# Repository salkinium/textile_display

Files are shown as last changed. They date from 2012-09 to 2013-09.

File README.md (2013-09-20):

Luminet2 Textile Display
========================

The Luminet2 Textile Display is a demonstrator for using the 
[Luminet2 Smart Pixel][luminet2] to display content on a flexible surface.
It consists out of an iOS App, many Luminet2 pixels and a textile connection matrix.

The project was done as a collaboration between [The Media Computing Group][i10] and
the [Institut für Textiltechnik][ITA] at RWTH Aachen University.

The main design goals of this project were to:

-	create a high density flexible display using Luminet2 pixels,
-	use a economically viable production technology,
-	design a scalable communication protocol.

The display is then to be integrated into a pillow case which protects the
display and encapsulates the battery and wireless communication adapter.

Design Concept
--------------

We received 80 Luminet2 pixels and decided to limit the display resolution to
8 x 8 pixels for a total of 64 pixels used.
The remaining pixels were used to testing connection techniques and buffer.

For the display to work, these four problems had to be solved:

1.	The pixels need to be connected with each other and placed on a textile
	using an industrial manufacturing technique
3.	A scalable method of communication between the pixels is required.
4.	The display should easily be connected to external data sources.

### Connection matrix

A matrix of flexible enameled copper wire was attached to jeans textile using
a CNC embroilment machine.
The wires have the function of fixing the Luminet2 PCB to the textile as
well as providing it with power and communication abilities.  
The design process is [described here][design].

### Communication

All pixels can exchange information between each other and an external node.  
Internally all nodes are attached to a wired ring bus, which is based on serial
communication and runs at high speed (0.5MBaud).
This bus is simply connected to a WiFly module which enables transparent
communication over WiFi using TCP/IP.  
Further information about [the embedded software][embedded].

### iOS app

An iOS application allow the drawing of custom 8x8 textures as well as
scrolling text in different colors and fonts.  
A UI description can be [found here][ui]

Organisation
------------

This repository is organized as follows:

-	The *connection* folder the python generators for the vector files for the 
	textile connection matrix.
- 	The *module* folder contains the embedded code for the Luminet2 pixels.
-	The *Textplay* folder contains the iOS App to control the display.

The Luminet2 Smart Pixel were designed by [Mariana Bocoi][bocoi].  
The connection matrix and embedded software were designed by [Niklas Hauser][hauser].

[luminet2]: http://hci.rwth-aachen.de/luminet2
[i10]: http://hci.rwth-aachen.de
[ita]: http://www.ita.rwth-aachen.de
[bocoi]: http://hci.rwth-aachen.de/bocoi
[hauser]: http://hci.rwth-aachen.de/hauser
[design]: https://amedeo.informatik.rwth-aachen.de/groups/textiledisplay/wiki/0f695/Textile_Connection_Matrix.html
[embedded]: https://amedeo.informatik.rwth-aachen.de/groups/textiledisplay/wiki/de7d8/Embedded_Software.html
[ui]: https://amedeo.informatik.rwth-aachen.de/groups/textiledisplay/wiki/711c2/Textplay_iOS_App.html

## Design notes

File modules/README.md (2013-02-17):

Luminet2 Pixel Software
=======================

The sources are compiled using the [XPCC library][xpcc], which is used for
GPIO, Processing, Build System and Serial Debugging.

Color generation
----------------

The color is generated using 8-bit PWM and a [gamma-corrected][gamma] look-up
table stored in flash memory.
This guarantees fast access times and correct color perception, however
generating very dark colors does not yield good results due to limited
PWM value range.

Photosensitive Diode
--------------------

Light intensity is measured using an oversampling and averaging algorithm.
The results are currently not used.

Communication
-------------

To transfer the bitmap data into the display, a simplified Resilient Packet Ring
protocol is used over serial.
The data is split into four 48-byte packets, which are sent as multicasts to
16 pixels each.
This allows for a small buffer on each pixel with acceptable overhead.

Each pixel has a unique 15bit address, and belongs to one of the four group
addresses, which are stored in EEPROM.
The bitmap values are sent as 8bit RGB values, and the node then calculated
the offset of its values in the data.

The protocol is currently not yet fully implemented, and still in development
at XPCC, however basic functionality, such as sending and receiving messages
works.

A more detailed description of the frame format [can be found here][rpr].

The pixels communicate directly with a WiFly module in ad-hoc mode, at a
baudrate of 0.5Mbps (500000 bits/s).

Firmware
--------

The sources are compiled using the [XPCC library][xpcc], which is used for
GPIO, Processing, Build System and Serial Debugging.  
Enter the `source` directory

	$ cd /path/to/textile_display/modules/source

To compile, execute:

	$ scons

To set the fuses on the microcontroller, execute:

	$ scons fuse

To flash the binary onto the microcontroller, execute:

	$ scons program

The fuses are set at 0xef (low), 0xd1 (high), 0x07 (extended).  
You can set the fuses manually using this command:

	$ avrdude -p atmega328p -c avrispmkii -P usb -u \
	-U hfuse:w:0xd1:m -U efuse:w:0x07:m -U lfuse:w:0xef:m

Installing XPCC
---------------

XPCC is provided as a git submodule, to use it run this in the root directory:

	$ git submodule init
	$ git submodule update

To install the XPCC build system on OS X (tested on Lion/Mountain Lion):

1.	Install [Homebrew][]:  
	`$ ruby -e "$(curl -fsSL https://raw.github.com/mxcl/homebrew/go)"`
2.	Install some dependencies:  
	`$ brew install scons python`  
	`$ pip install lxml jinja2`
3.	Install the latest precompiled version of [avr-gcc from ObDev][obdev].

To install the XPCC build system on Linux (tested on Ubuntu 12.04):

	$ sudo apt-get update
	$ sudo apt-get install python scons python-jinja2 python-lxml \
	gcc-avr binutils-avr avr-libc avrdude

Extensive information on installing [the XPCC build system can be found here][xpcc-install].

[xpcc]: https://github.com/roboterclubaachen/xpcc
[gamma]: http://en.wikipedia.org/wiki/Gamma_correction
[rpr]: https://raw.github.com/roboterclubaachen/xpcc/feature/resilient_packet_ring/src/xpcc/driver/connectivity/rpr.hpp
[homebrew]: http://mxcl.github.com/homebrew/
[obdev]: http://www.obdev.at/products/crosspack/download.html
[xpcc-install]: http://xpcc.kreatives-chaos.com/install.html

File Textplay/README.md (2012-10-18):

iOS Controller App
==================

The app is designed to work on an (Retina) 3.5 inch display and features a simple
drawing mode and a scrolling text mode with a selection of four fonts.

It has three views:

- the display view shows the current display frame, connection status
	and allows for text input.
	You can clear the matrix or pause display refresh.
- the color picker lets you choose a color.
- the settings view lets you connect to an IP, select the text font and text
	scrolling verlocity.

The Color Picker was made by [Ryota Hayashi][color] and slightly modified.
The font and font renderer is taken from [XPCC][xpcc].
Data transmission is done via [AsyncSocket][socket].
The Font Picker is from [Tim Cinel][picker]

[color]: https://github.com/hayashi311/Color-Picker-for-iOS
[xpcc]: https://github.com/roboterclubaachen/xpcc
[socket]: https://github.com/robbiehanson/CocoaAsyncSocket
[picker]: https://github.com/TimCinel/ActionSheetPicker

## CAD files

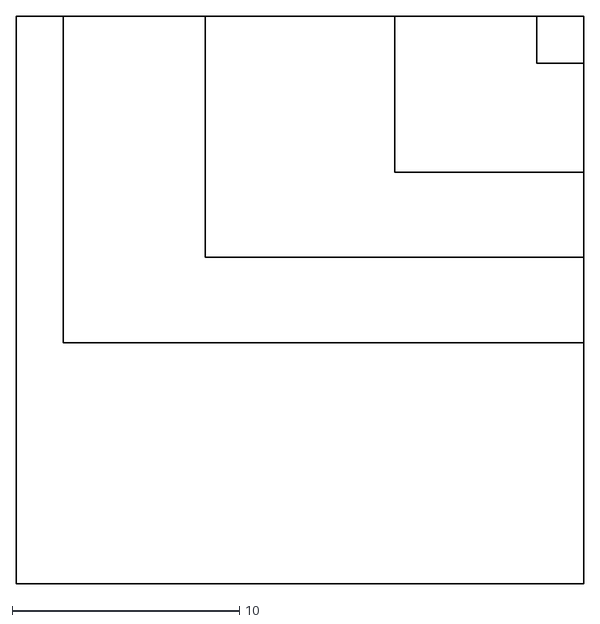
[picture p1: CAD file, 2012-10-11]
connection/matrix/matrix_0x1.dxf
25.0 x 25.0

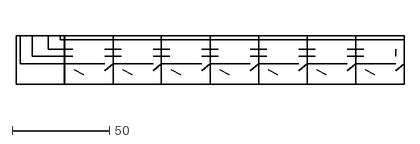
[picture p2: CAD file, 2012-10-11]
connection/matrix/matrix_7x1.dxf
200.0 x 25.0

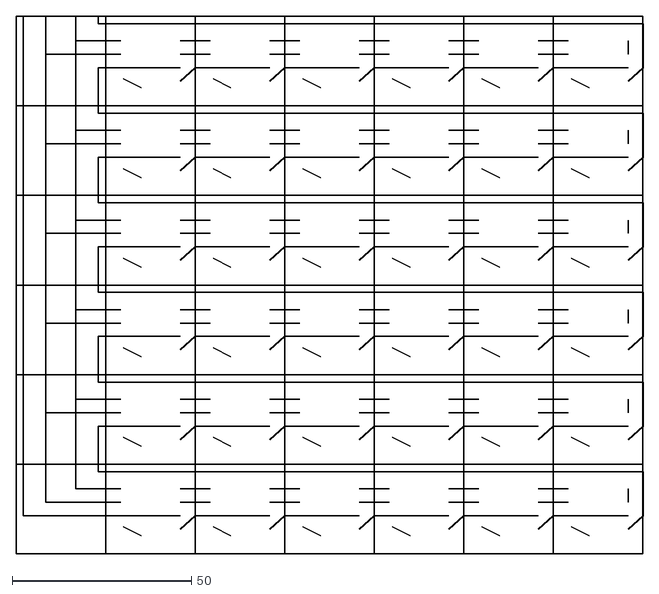
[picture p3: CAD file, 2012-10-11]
connection/matrix/matrix_6x6.dxf
175.0 x 150.0

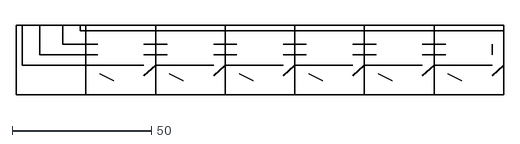
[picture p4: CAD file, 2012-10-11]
connection/matrix/matrix_6x1.dxf
175.0 x 25.0

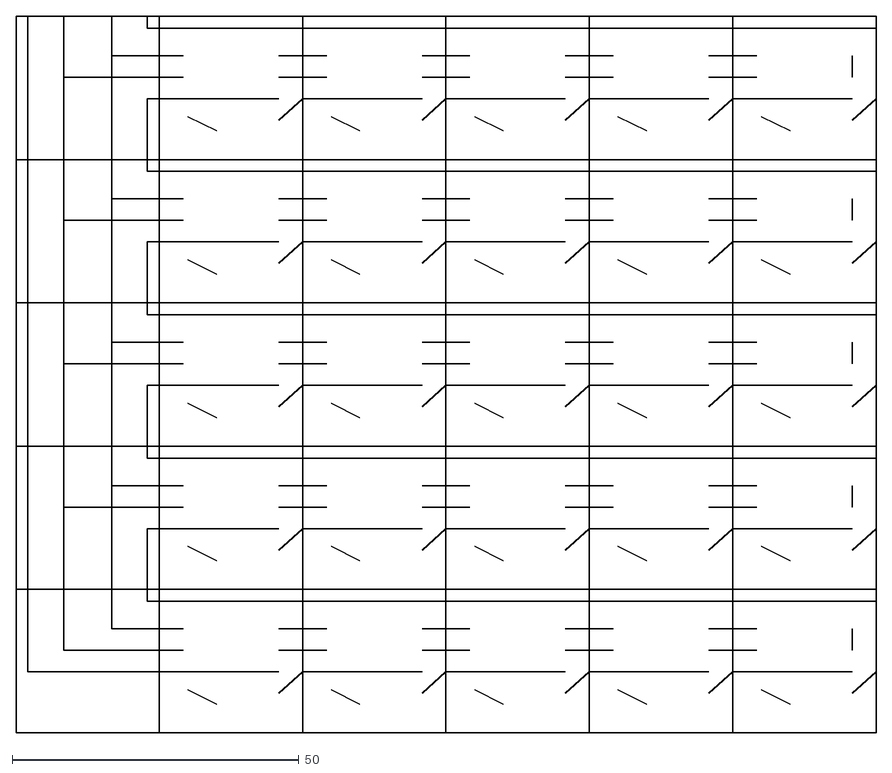
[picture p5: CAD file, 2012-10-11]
connection/matrix/matrix_5x5.dxf
150.0 x 125.0

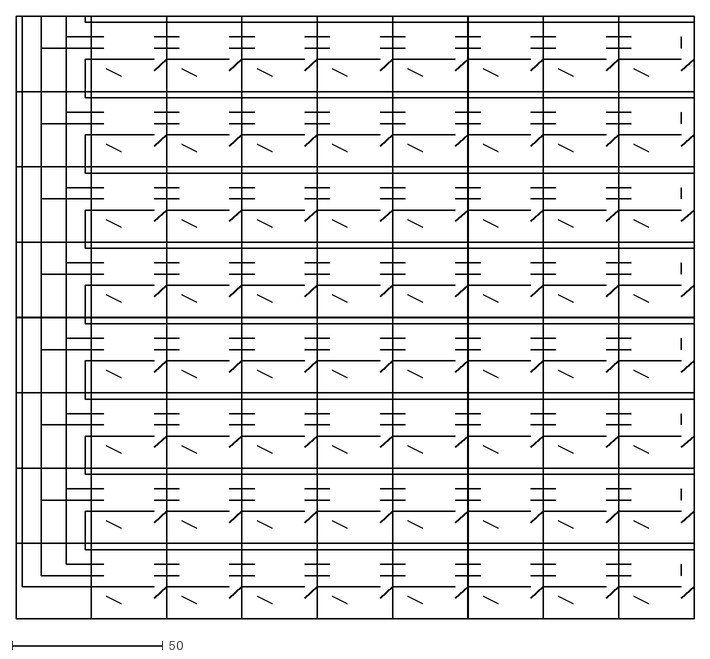
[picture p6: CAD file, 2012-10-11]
connection/matrix/matrix_8x8.dxf
225.0 x 200.0

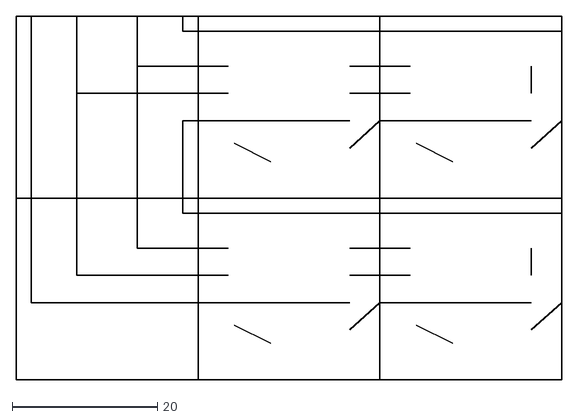
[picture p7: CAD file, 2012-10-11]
connection/matrix/matrix_2x2.dxf
75.0 x 50.0

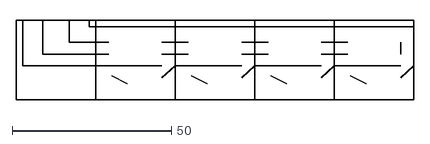
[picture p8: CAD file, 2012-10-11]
connection/matrix/matrix_4x1.dxf
125.0 x 25.0

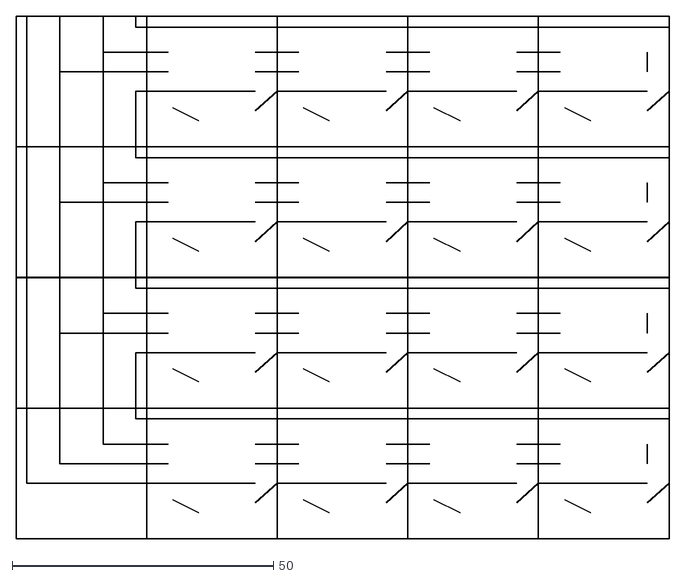
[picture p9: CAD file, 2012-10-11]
connection/matrix/matrix_4x4.dxf
125.0 x 100.0

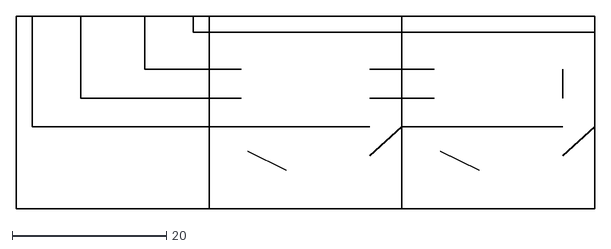
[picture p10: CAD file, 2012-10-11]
connection/matrix/matrix_2x1.dxf
75.0 x 25.0

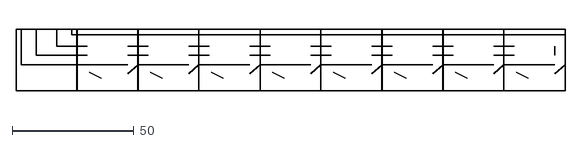
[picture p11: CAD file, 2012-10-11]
connection/matrix/matrix_8x1.dxf
225.0 x 25.0

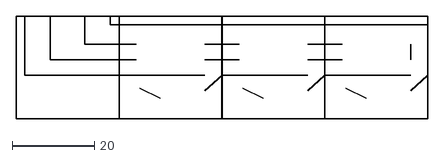
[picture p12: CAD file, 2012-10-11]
connection/matrix/matrix_3x1.dxf
100.0 x 25.0

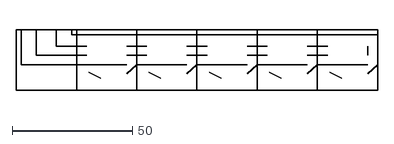
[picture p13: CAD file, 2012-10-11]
connection/matrix/matrix_5x1.dxf
150.0 x 25.0

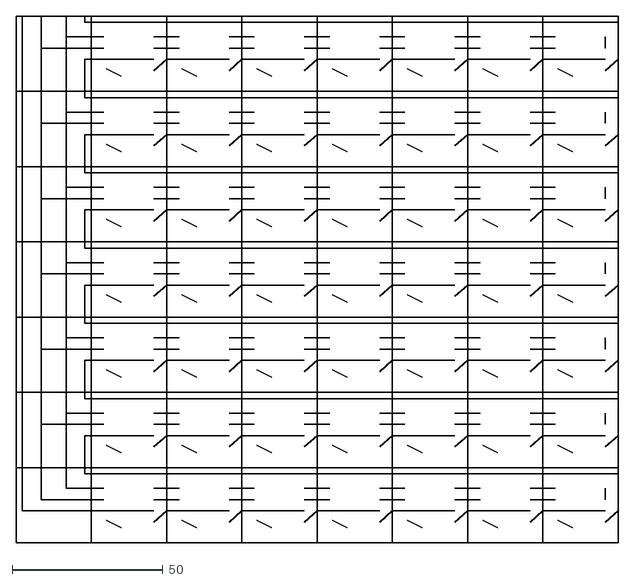
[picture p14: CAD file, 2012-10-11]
connection/matrix/matrix_7x7.dxf
200.0 x 175.0

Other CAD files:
connection/matrix/matrix_1x1.dxf
connection/matrix/matrix_3x3.dxf

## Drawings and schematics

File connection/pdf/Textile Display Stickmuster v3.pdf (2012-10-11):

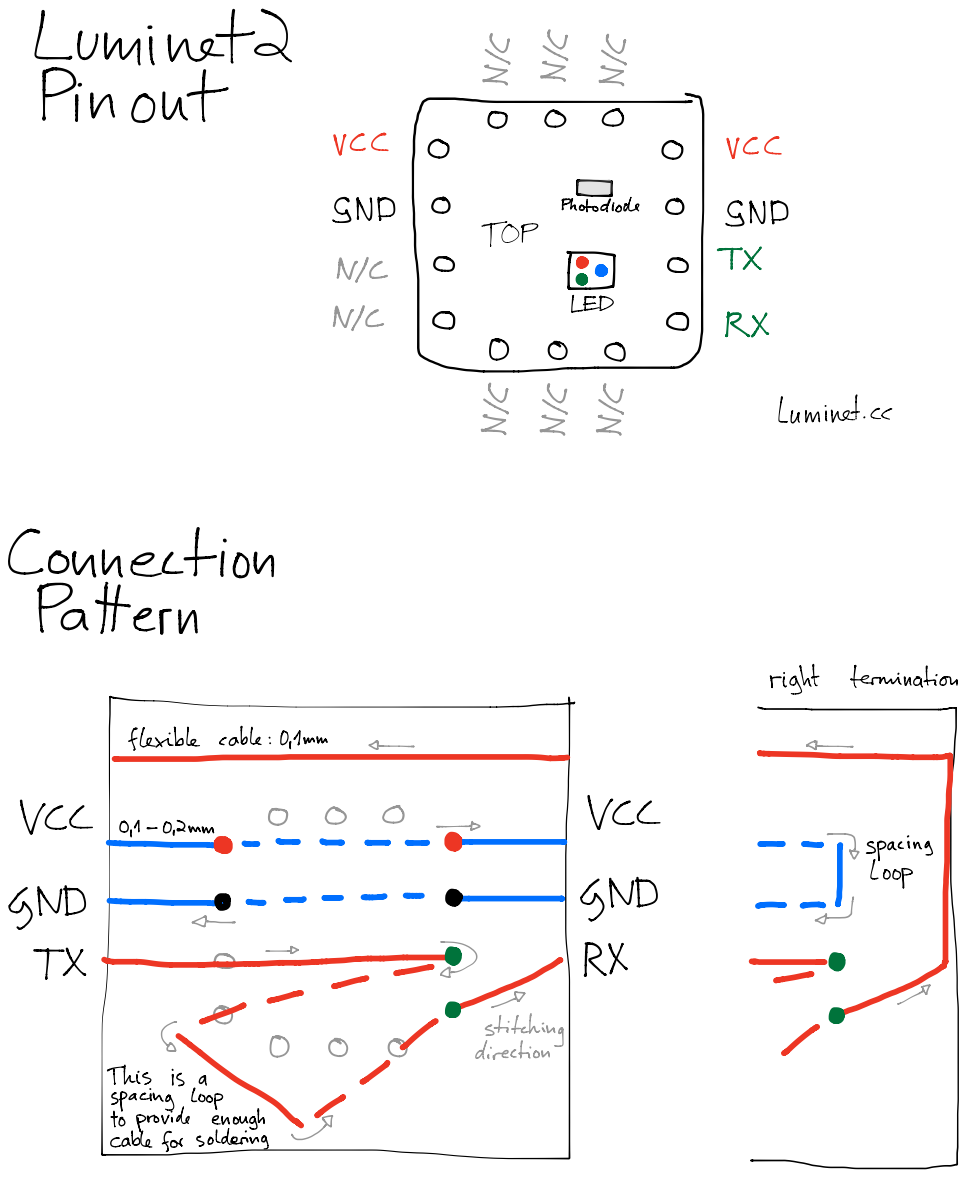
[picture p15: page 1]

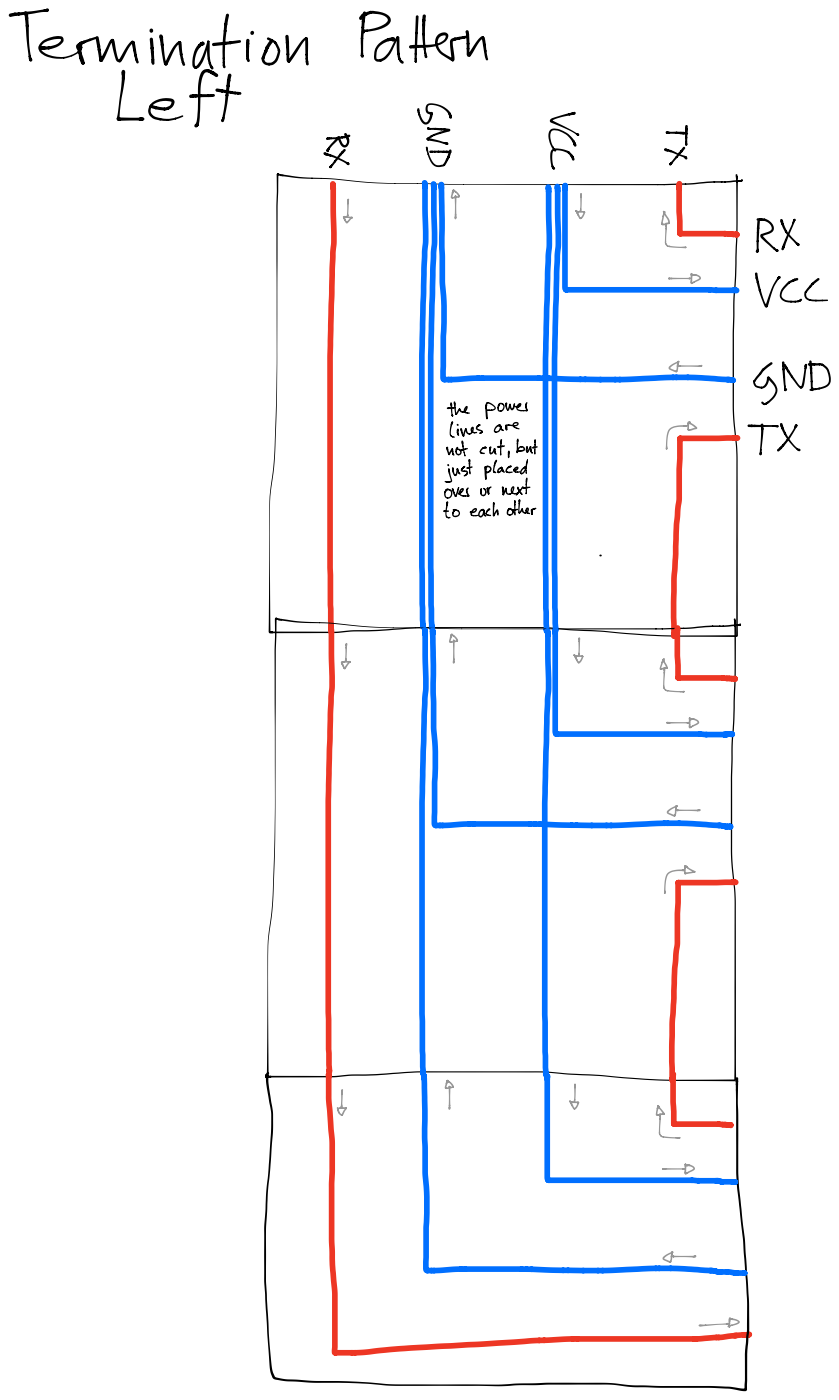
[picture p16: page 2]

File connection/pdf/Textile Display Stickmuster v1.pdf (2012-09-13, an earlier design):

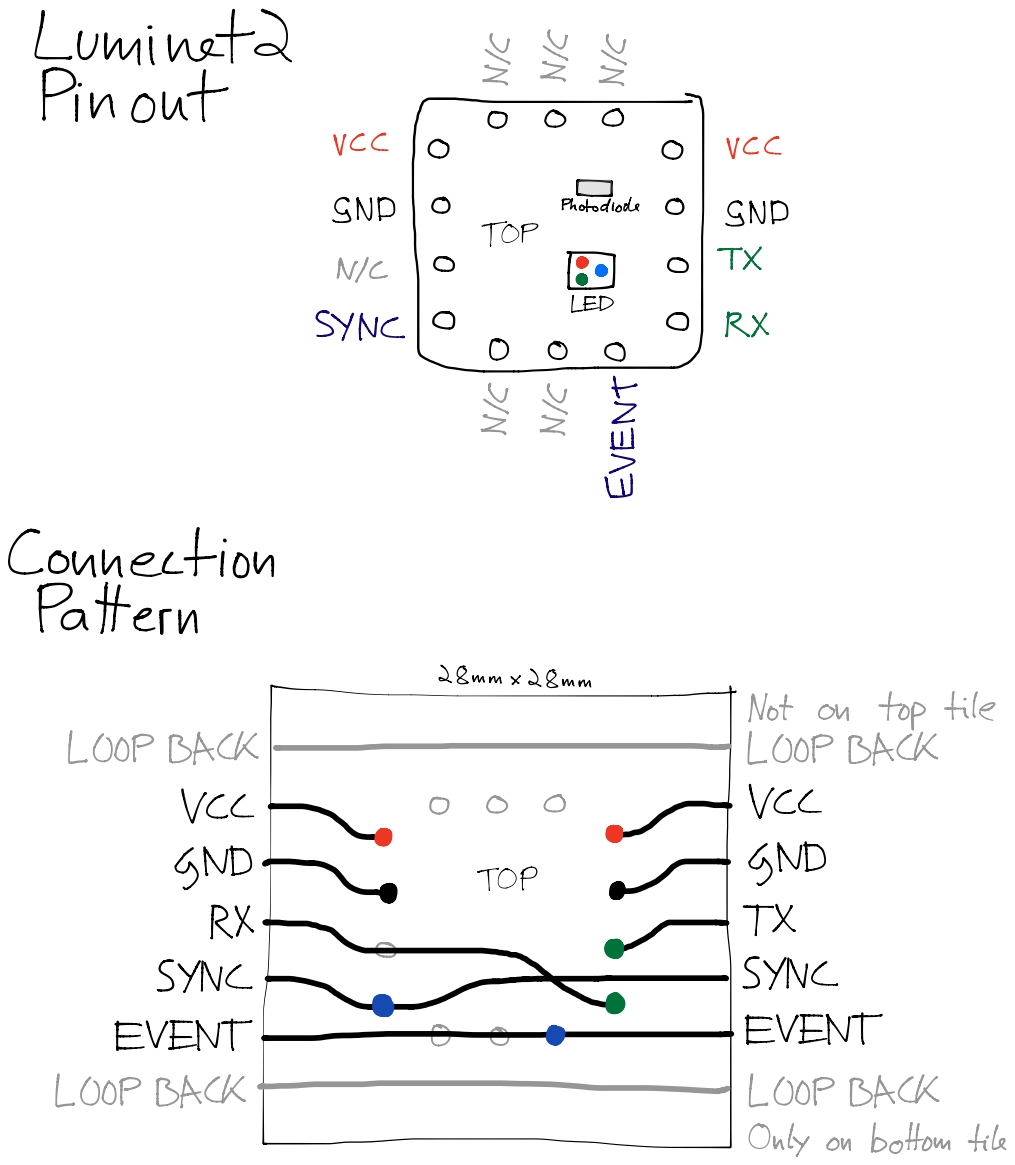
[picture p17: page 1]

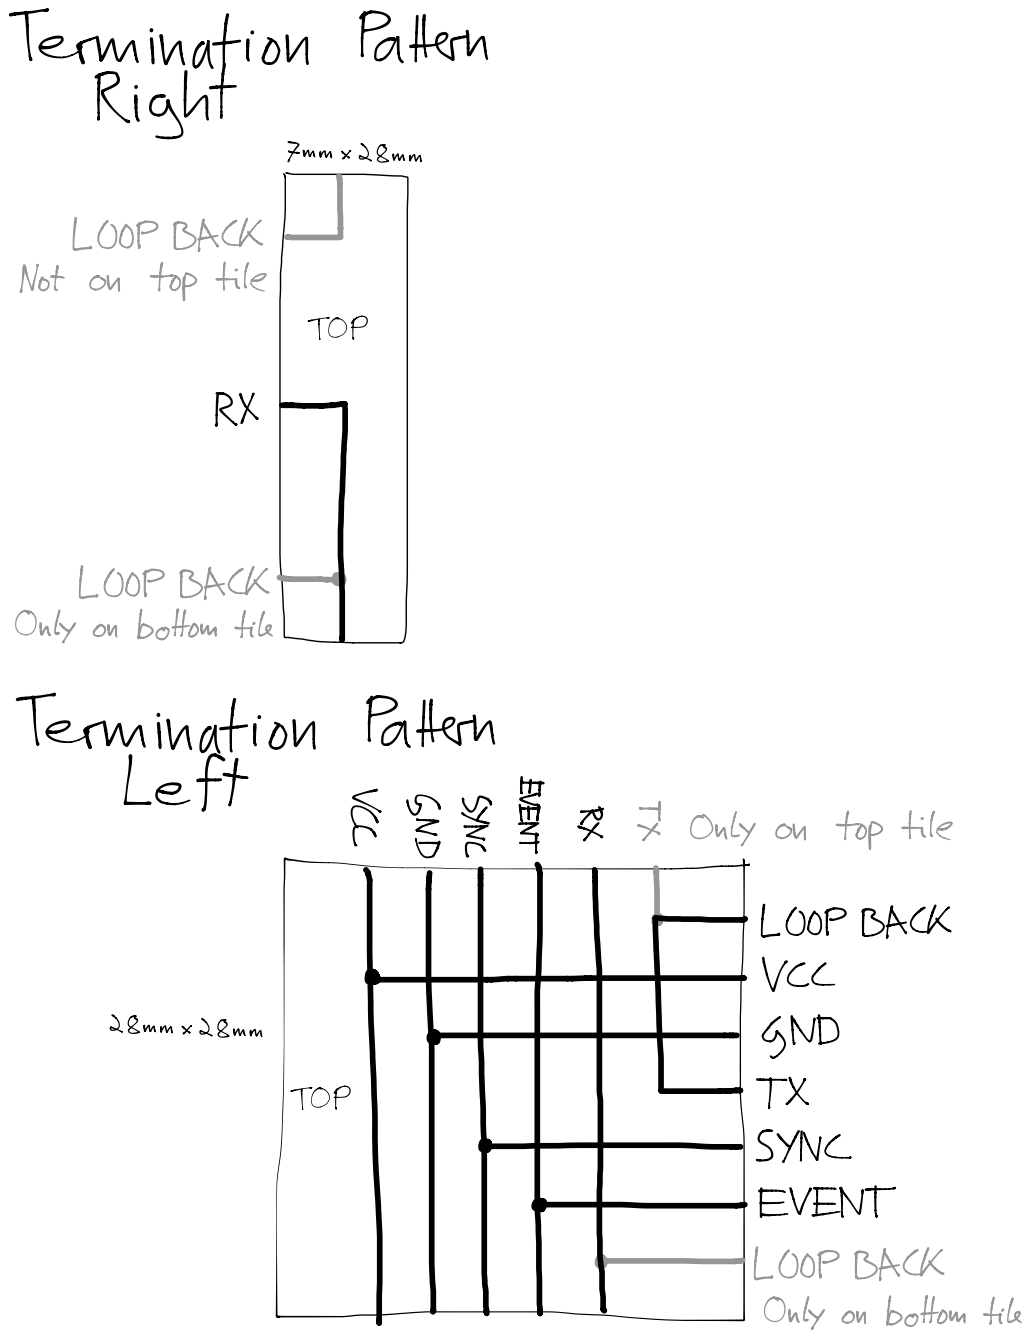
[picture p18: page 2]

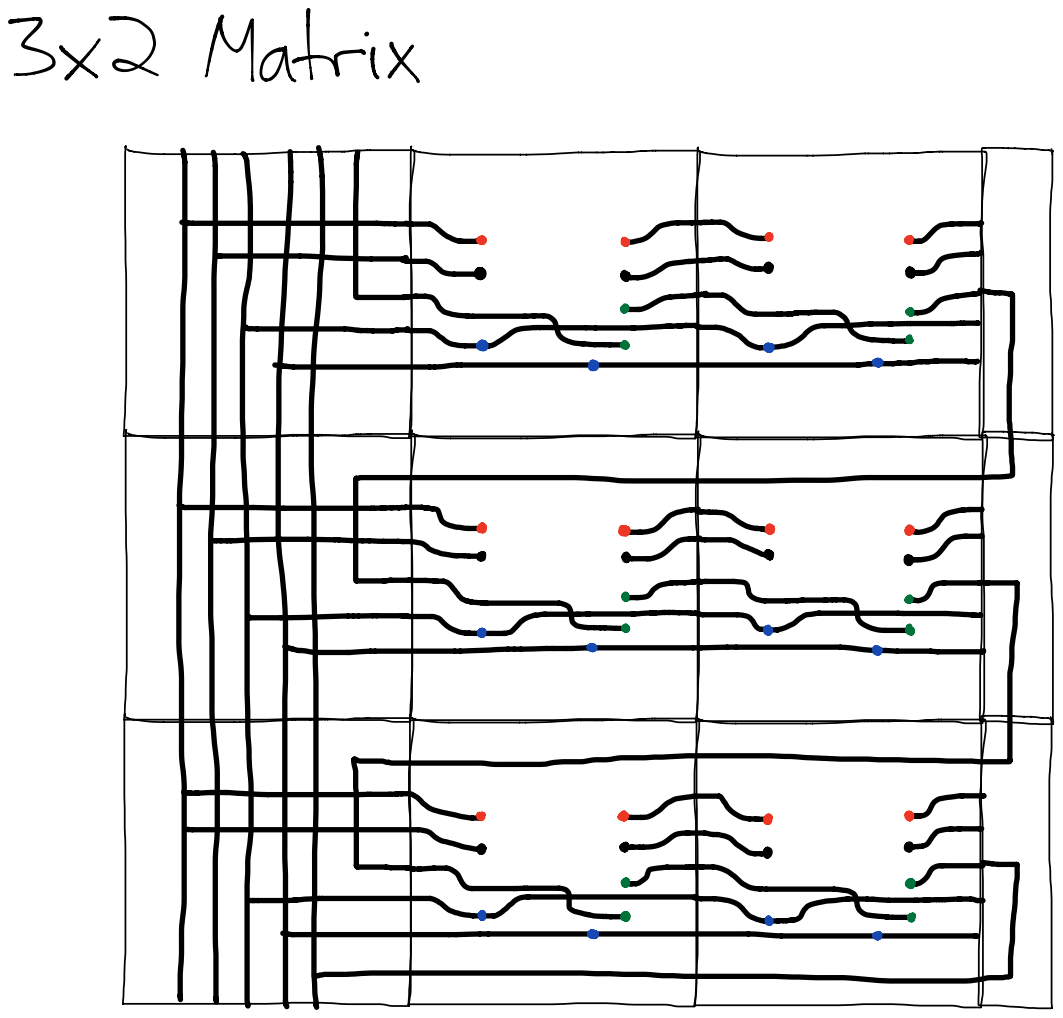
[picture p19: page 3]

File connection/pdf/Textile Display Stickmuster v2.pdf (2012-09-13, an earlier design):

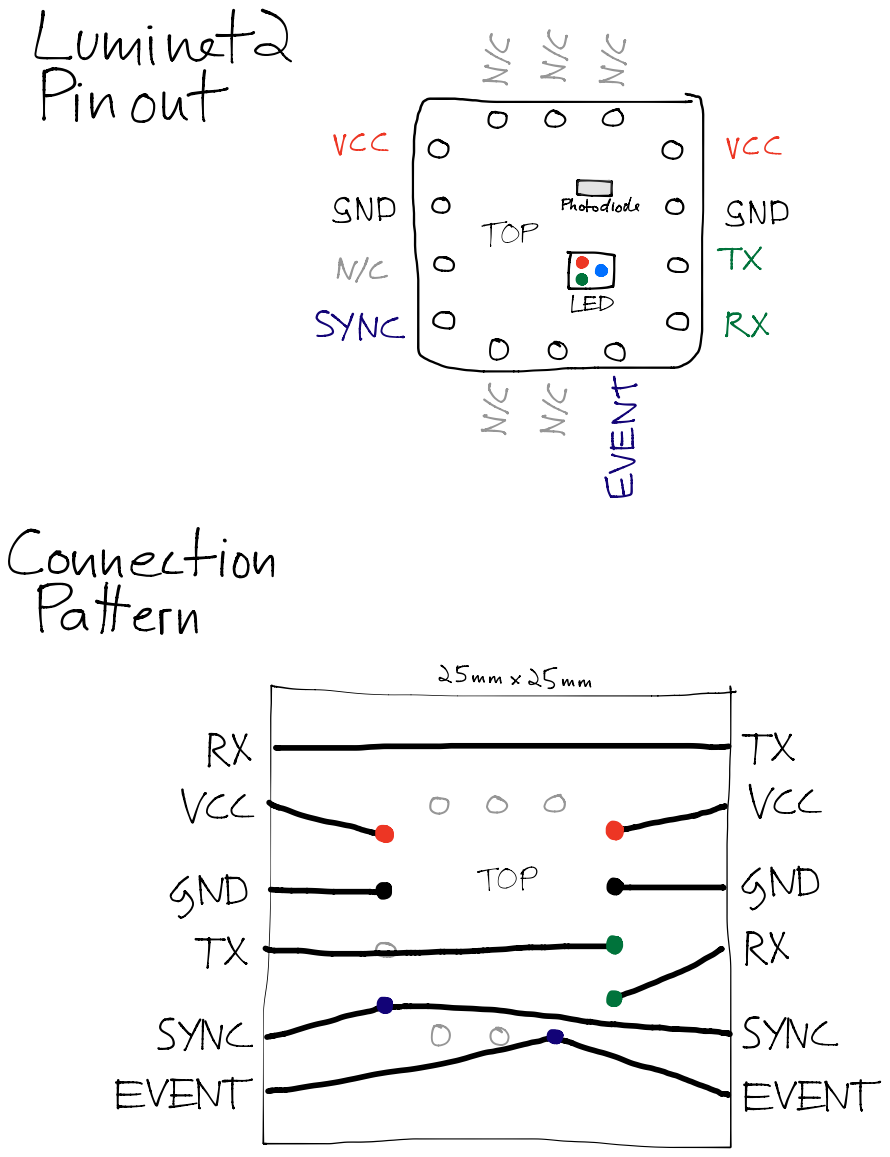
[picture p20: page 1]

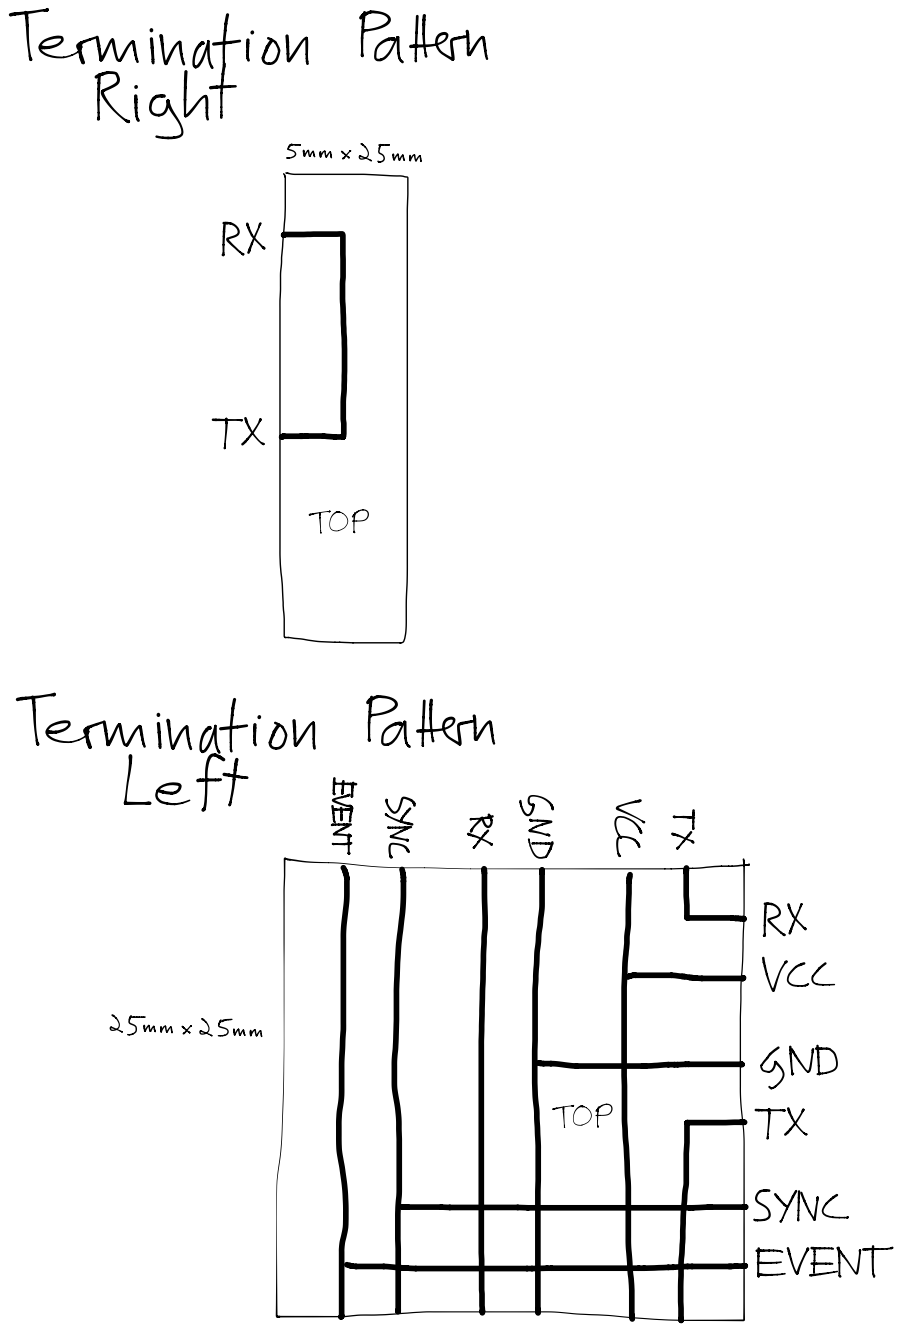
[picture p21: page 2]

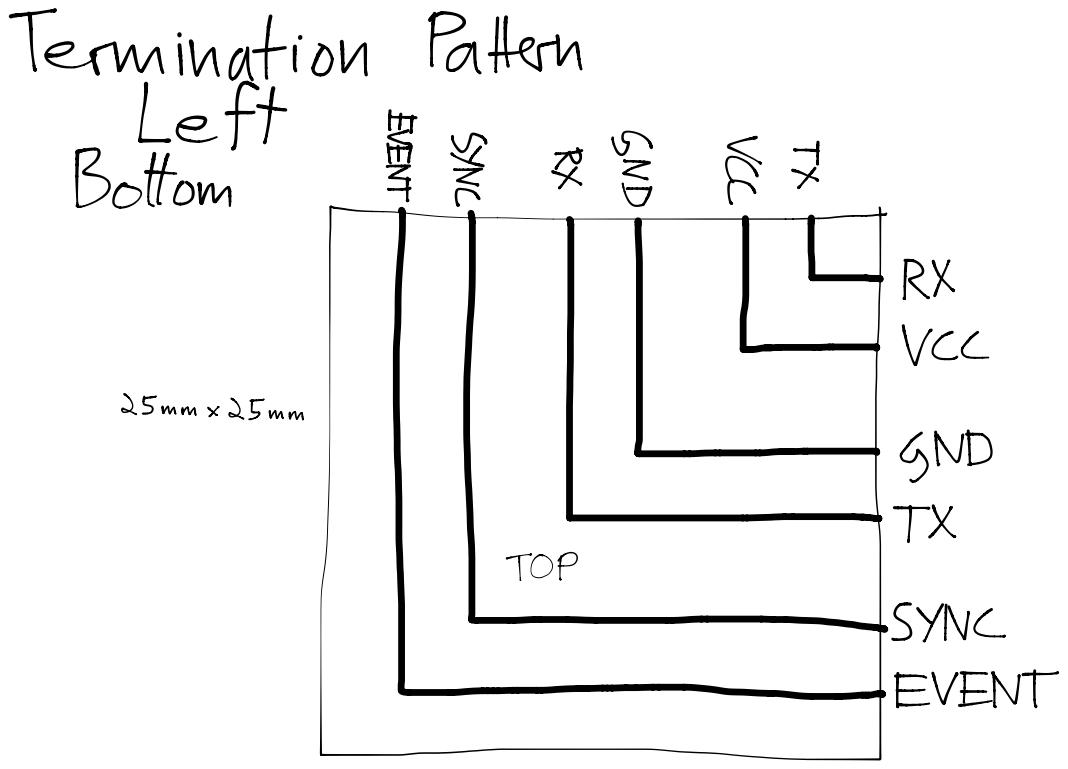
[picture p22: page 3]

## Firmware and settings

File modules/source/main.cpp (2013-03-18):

// coding: utf-8
#include <xpcc/architecture/platform.hpp>
#include <xpcc/architecture/driver.hpp>
#include <xpcc/workflow.hpp>
#include <stdlib.h>

#define IS_DREAM_GENERATOR 1

// IO #########################################################################
GPIO__IO(SENSOR1, C, 0);			// ADC0
GPIO__IO(SENSOR2, C, 1);			// ADC1
GPIO__IO(SENSOR3, C, 2);			// ADC2
GPIO__INPUT(LIGHT_SENSOR, C, 3);	// ADC3

GPIO__INPUT(SYNC, D, 2);			// INT0
GPIO__IO(EVENT, D, 3);				// INT1

GPIO__OUTPUT(RED, B, 1);			// OCR1AL
GPIO__OUTPUT(GREEN, D, 6);			// OCR0A
GPIO__OUTPUT(BLUE, D, 5);			// OCR0B

// COLORS #####################################################################
#include "rgbLed.hpp"
RgbLed led;

// PHOTOSENSITIVE DIODE #######################################################
typedef xpcc::atmega::AdcInterrupt Adc;
uint8_t adcMap[1] = {3};
typedef xpcc::atmega::AnalogSensors< Adc,1,3 > photo;
uint16_t photoData;
xpcc::PeriodicTimer<> photoTimer(200);
uint16_t photoRequestSource = 0;
bool photoSensingInProgress = false;

// COMMUNICATION ##############################################################
typedef xpcc::atmega::BufferedUart0 primaryUart;
primaryUart uart(500000);

//#include <xpcc/io/iodevice_wrapper.hpp>
//#include <xpcc/io/iostream.hpp>
//xpcc::IODeviceWrapper< primaryUart > device(uart);
//xpcc::IOStream stream(device);

#if IS_DREAM_GENERATOR
xpcc::Timeout<> redT(29);
xpcc::Timeout<> greenT(21);
xpcc::Timeout<> blueT(38);
RgbColor fadeC = {25,8,200};
RgbColor counterC = {25,8,200};

xpcc::Timeout<> colorT(3000);
RgbColor maxC = {255,255,255};
RgbColor maxFadeC = {255,255,255};

xpcc::PeriodicTimer<> timer(15);
xpcc::Timeout<> receiverTimeout(15000);
#endif

#include <avr/eeprom.h>
uint8_t volatileGroupPixel;
FadingColor colorBuffer = {0, {0, 0, 0}};

#include <xpcc/driver/connectivity/rpr.hpp>

class Communicator : public xpcc::rpr::Callable
{
public:
	void
	setColor(xpcc::rpr::Transmitter& /*node*/, xpcc::rpr::Message *message)
	{
		colorBuffer = *reinterpret_cast<FadingColor *>(message->payload);
	}
	
	void
	setGroupColor(xpcc::rpr::Transmitter& /*node*/, xpcc::rpr::Message *message)
	{
		colorBuffer.color.red = *(message->payload + volatileGroupPixel*3);
		colorBuffer.color.green = *(message->payload + volatileGroupPixel*3 + 1);
		colorBuffer.color.blue = *(message->payload + volatileGroupPixel*3 + 2);
#if IS_DREAM_GENERATOR
		receiverTimeout.restart(15000);
#endif
	}
	
	void
	swapColorBuffer(xpcc::rpr::Transmitter& /*node*/, xpcc::rpr::Message */*message*/)
	{
		if (!photoSensingInProgress)
		{
			led.fadeToRgbColorValue(0, colorBuffer.color.red, colorBuffer.color.green, colorBuffer.color.blue);
		}
	}
	
	void
	getID(xpcc::rpr::Transmitter& node, xpcc::rpr::Message *message)
	{
		// colomns, rows, groupsize, groupid
		uint8_t buffer[4] = {8,8,16,volatileGroupPixel};
		node.unicastMessage(message->source, common::command::ANSWER_ID, buffer, 4);
	}
	
	void
	getPhoto(xpcc::rpr::Transmitter& /*node*/, xpcc::rpr::Message *message)
	{
		if (!photoSensingInProgress)
		{
			// turn off LEDs
			led.fadeToRgbColorValue(0, 0, 0, 0);
			photoSensingInProgress = true;
			// start taking a measurement
			photo::readSensors();
			photoRequestSource = message->source;
		}
	}
};
Communicator comm;

FLASH_STORAGE(xpcc::rpr::Listener listenList[]) =
{
	RPR__LISTEN(xpcc::rpr::MESSAGE_TYPE_UNICAST,	xpcc::rpr::ADDRESS_ANY, common::command::SET_COLOR,		comm, Communicator::setColor),
	RPR__LISTEN(xpcc::rpr::MESSAGE_TYPE_MULTICAST,	xpcc::rpr::ADDRESS_ANY, common::command::SET_COLOR,		comm, Communicator::setGroupColor),
	RPR__LISTEN(xpcc::rpr::MESSAGE_TYPE_BROADCAST,	xpcc::rpr::ADDRESS_ANY, common::command::SWAP_COLOR,	comm, Communicator::swapColorBuffer),
	RPR__LISTEN(xpcc::rpr::MESSAGE_TYPE_UNICAST,	xpcc::rpr::ADDRESS_ANY, common::command::REQUEST_ID,	comm, Communicator::getID),
	RPR__LISTEN(xpcc::rpr::MESSAGE_TYPE_UNICAST,	xpcc::rpr::ADDRESS_ANY, common::command::REQUEST_PHOTO,	comm, Communicator::getPhoto),
	RPR__LISTEN(xpcc::rpr::MESSAGE_TYPE_BROADCAST,	xpcc::rpr::ADDRESS_ANY, common::command::REQUEST_PHOTO,	comm, Communicator::getPhoto),
};

xpcc::rpr::Node< xpcc::rpr::Interface< primaryUart > >
rprNode(xpcc::accessor::asFlash(listenList),
		sizeof(listenList) / sizeof(xpcc::rpr::Listener));
// if you change the order of the pointers, you will have to program the eeprom again.
uint16_t EEMEM NonVolatileAddress = 0;
uint16_t EEMEM NonVolatileGroupAddress = common::group::GROUP0;
uint8_t EEMEM NonVolatileGroupPixel = 0;

// SYS TICK ###################################################################
ISR(TIMER2_COMPA_vect)
{
	xpcc::Clock::increment();
}

MAIN_FUNCTION // ##############################################################
{
	// Fast PWM Mode on timer 0, non-inverting mode
	// set OCnX at BOTTOM, clear OCnX on Compare Match
    TCCR0A = (1<<WGM01)|(1<<WGM00);
	// 8000kHz / 8 / 255 = 3.92kHz ~ 0.255ms
    TCCR0B = (1<<CS01);
	
	// Fast PWM Mode on timer 1, non-inverting mode, restricted to 8 bits
	//set OCnA at BOTTOM, clear OCnA on Compare Match
	TCCR1A = (1<<WGM10);
	// 8000kHz / 8 / 255 = 3.92kHz ~ 0.255ms
	TCCR1B = (1<<WGM12)|(1<<CS11);
	
	// CTC mode on timer 2
	TCCR2A = (1<<WGM21);
	// 8000kHz / 32 / 250 = 1kHz ~ 1ms
	TCCR2B = (1<<CS21)|(1<<CS20);
	// TOP of 250
	OCR2A = 250;
	// enable compare interrupt
	TIMSK2 = (1<<OCIE2A);
	
	// turn off all LEDs
	BLUE::setOutput(xpcc::gpio::LOW);
	RED::setOutput(xpcc::gpio::LOW);
	GREEN::setOutput(xpcc::gpio::LOW);
	
	SENSOR1::setInput();
	SENSOR2::setInput();
	SENSOR3::setInput();
	LIGHT_SENSOR::setInput();
	
	// set up the oversampling of the photosensitive diode
	Adc::initialize(xpcc::atmega::Adc::REFERENCE_AREF, xpcc::atmega::Adc::PRESCALER_32);
	photo::initialize(adcMap, &photoData);
	
	volatileGroupPixel = eeprom_read_byte(&NonVolatileGroupPixel);
	rprNode.setAddress(eeprom_read_word(&NonVolatileAddress), eeprom_read_word(&NonVolatileGroupAddress));
	
#if IS_DREAM_GENERATOR
	srand(xpcc::atmega::Adc::readChannel(3));
#endif
	
	xpcc::atmega::enableInterrupts();
	
	// small test program, that cycles through the RGB LEDs, so one can spot
	// problematic nodes immidiately, takes about 2200 ms
	xpcc::Timeout<> testT(200);
	uint8_t testStatus = 0;
	
	while (testStatus < 5)
	{
		if (testT.isExpired())
		{
			switch (testStatus)
			{
				case 0:
					led.fadeToRgbColorValue(200,50,0,0);
					testT.restart(500);
					testStatus = 1;
					break;
					
				case 1:
					led.fadeToRgbColorValue(200,0,50,0);
					testT.restart(500);
					testStatus = 2;
					break;
					
				case 2:
					led.fadeToRgbColorValue(200,0,0,50);
					testT.restart(500);
					testStatus = 3;
					break;
					
				case 3:
					led.fadeToRgbColorValue(200,50,50,50);
					testT.restart(500);
					testStatus = 4;
					break;
					
				default:
					led.fadeToRgbColorValue(0,0,0,0);
					testT.stop();
					testStatus = 5;
					break;
			}
		}
		led.update();
	}
	
	while (1)
	{
		rprNode.update();
		
#if IS_DREAM_GENERATOR
		if (receiverTimeout.isExpired())
		{
			if (colorT.isExpired())
			{
				static uint8_t maxState = 0;
				
				switch (maxState++)
				{
					case 0:
						maxC.red = 254;
						maxC.green = 100;
						maxC.blue = 100;
						break;
						
					case 1:
						maxC.red = 100;
						maxC.green = 254;
						maxC.blue = 100;
						break;
						
					case 2:
						maxC.red = 100;
						maxC.green = 100;
						maxC.blue = 254;
						break;
						
					case 3:
						maxC.red = 150;
						maxC.green = 30;
						maxC.blue = 30;
						break;
						
					case 4:
						maxC.red = 30;
						maxC.green = 150;
						maxC.blue = 30;
						break;
						
					case 5:
						maxC.red = 30;
						maxC.green = 30;
						maxC.blue = 150;
						break;
						
					case 6:
						maxC.red = 200;
						maxC.green = 1;
						maxC.blue = 1;
						break;
						
					case 7:
						maxC.red = 1;
						maxC.green = 200;
						maxC.blue = 1;
						break;
						
					case 8:
						maxC.red = 1;
						maxC.green = 1;
						maxC.blue = 200;
						break;
						
					default:
						maxC.red = 254;
						maxC.green = 254;
						maxC.blue = 254;
						maxState = 0;
						break;
						
				}
				// max about 8 secs
				colorT.restart(5000);
			}
			
			if (redT.isExpired())
			{
				counterC.red -= 1;
				fadeC.red = counterC.red;
				if (counterC.red > maxFadeC.red)
					fadeC.red = maxFadeC.red;
					
					redT.restart(rand()%60);
					}
			if (greenT.isExpired())
			{
				counterC.green -= 1;
				fadeC.green = counterC.green;
				if (counterC.green > maxFadeC.green)
					fadeC.green = maxFadeC.green;
					greenT.restart(rand()%70);
					}
			if (blueT.isExpired())
			{
				counterC.blue -= 1;
				fadeC.blue = counterC.blue;
				if (counterC.blue > maxFadeC.blue)
					fadeC.blue = maxFadeC.blue;
					blueT.restart(rand()%77);
					}
			
			if (timer.isExpired())
			{
				static uint8_t buffer[48*4];
				
				for(uint8_t i=0; i<16*4; i++)
				{
					buffer[i*3] = fadeC.red + (i+32)*8;
					buffer[i*3+1] = fadeC.green + (i+32)*10;
					buffer[i*3+2] = fadeC.blue + (i+32)*12;
				}
				
				colorBuffer.color.red = *(buffer + volatileGroupPixel*3);
				colorBuffer.color.green = *(buffer + volatileGroupPixel*3 + 1);
				colorBuffer.color.blue = *(buffer + volatileGroupPixel*3 + 2);
				
				rprNode.multicastMessage(common::group::GROUP0, common::command::SET_COLOR, buffer, 48);
				rprNode.multicastMessage(common::group::GROUP1, common::command::SET_COLOR, buffer+48, 48);
				rprNode.multicastMessage(common::group::GROUP2, common::command::SET_COLOR, buffer+48*2, 48);
				rprNode.multicastMessage(common::group::GROUP3, common::command::SET_COLOR, buffer+48*3, 48);
				rprNode.broadcastMessage(common::command::SWAP_COLOR, 0, 0);
				
				led.fadeToRgbColorValue(0, colorBuffer.color.red, colorBuffer.color.green, colorBuffer.color.blue);
				
				
				if (maxFadeC.red > maxC.red)
					maxFadeC.red--;
				else if (maxFadeC.red < maxC.red)
					maxFadeC.red++;
				
				if (maxFadeC.green > maxC.green)
					maxFadeC.green--;
				else if (maxFadeC.green < maxC.green)
					maxFadeC.green++;
				
				if (maxFadeC.blue > maxC.blue)
					maxFadeC.blue--;
				else if (maxFadeC.blue < maxC.blue)
					maxFadeC.blue++;
			}
		}
#endif
		led.update();
	}
}

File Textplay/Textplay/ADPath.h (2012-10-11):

//
//  CAPath.h
//  
//
//  Created by Niklas Hauser on 3/11/11.
//  Copyright 2011 Niklas Hauser. All rights reserved.
//

#import <QuartzCore/QuartzCore.h>

@interface ADPath : NSObject

@property (nonatomic) CGMutablePathRef path;
@property (strong, nonatomic) UIColor *lineColor;
@property (strong, nonatomic) UIColor *fillColor;
@property (nonatomic) CGFloat lineWidth;
@property (nonatomic) CGLineCap lineCap;
@property (nonatomic) CGLineJoin lineJoin;
@property (nonatomic) BOOL shadow;

-(id)initWithPath:(CGMutablePathRef)_path withLineColor:(UIColor *)color
	withLineWidth:(CGFloat)width withShadow:(BOOL)shadow;

-(void)addPath:(CGMutablePathRef)otherPath;
-(void)addLayerPath:(ADPath *)layerPath;

-(void)drawPathInContext:(CGContextRef)ctx;
-(void)drawPathInContext:(CGContextRef)ctx withTransformation:(const CGAffineTransform *)m;
-(void)drawPathInContext:(CGContextRef)ctx withTranslation:(CGPoint)translate;
-(void)drawPathInContext:(CGContextRef)ctx addPath:(CGMutablePathRef)otherPath;

-(BOOL)fillPathInContext:(CGContextRef)ctx;
-(void)fillPathInContext:(CGContextRef)ctx withTranslation:(CGPoint)translate;


+(void)drawPath:(CGPathRef)path inContext:(CGContextRef)ctx inColor:(UIColor *)color
   withLineWidth:(CGFloat)width withLineCap:(CGLineCap)cap withLineJoin:(CGLineJoin)join withShadow:(BOOL)shadow;
+(void)drawRect:(CGRect)rect inContext:(CGContextRef)ctx inColor:(UIColor *)color
   withLineWidth:(CGFloat)width withLineJoin:(CGLineJoin)join withShadow:(BOOL)shadow;
+(void)drawEllipse:(CGRect)rect inContext:(CGContextRef)ctx inColor:(UIColor *)color
	  withLineWidth:(CGFloat)width withShadow:(BOOL)shadow;

+(void)fillPath:(CGPathRef)path inContext:(CGContextRef)ctx withColor:(UIColor *)color;
+(void)fillRect:(CGRect)rect inContext:(CGContextRef)ctx inColor:(UIColor *)color;
+(void)fillEllipse:(CGRect)rect inContext:(CGContextRef)ctx inColor:(UIColor *)color;

@end

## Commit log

2012-08-17 Initial commit. Add .gitignore.
    [Luminet2_2_0.brd, Luminet2_2_0.sch, Luminet2_Adapter.brd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]
2012-08-17 Add STM32 project.
    [project.cfg, stm32f4x.cfg]
2012-09-13 Rename pcbs/ folder to pcb/.
    [Luminet2_2_0.brd, Luminet2_2_0.sch, Luminet2_Adapter.brd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]
2012-09-13 Streamline the textile matrix generation. Now with correct scale and better routing.
    [matrix_0x1.dxf, matrix_1x1.dxf, matrix_2x1.dxf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]
2012-09-13 Add code to test the RPR connection. Works stable so far.
    [project.cfg]
2012-09-17 Remove debug marcos from test_node. Make group addressing work. Add permanent values stored in EEPROM. Generate simple test pattern to test functionality.
    [project.cfg]
2012-10-11 Reduce cables in Tiles and Terminations to power and communication, and optimise for embroilment.
    [matrix_0x1.dxf, matrix_1x1.dxf, matrix_2x1.dxf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]
2012-10-18 Move test_node/ to luminet/.
    [project.cfg]
2012-10-18 Remove pcb/ folder. Move pdf/ folder to connection/pdf/.
    [Luminet2_2_0.brd, Luminet2_2_0.sch, Luminet2_Adapter.brd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]
2012-11-26 Optimize RGB LED fading controllers, so they work much faster. Add methods to read out the photosensitive diode.
2013-02-16 Add documentation about modules and use of xpcc. Add xpcc as submodule. Remove STM32 test, and clean up luminet folder.
    [project.cfg, stm32f4x.cfg]
2013-02-17 Add documentation about XPCC usage. Rename luminet folder to source.
    [project.cfg]
2013-03-18 Fix dream code to also set own led.
    [main.cpp]
2013-03-18 Fix screen saver prevention code in app.
    [project.cfg]
